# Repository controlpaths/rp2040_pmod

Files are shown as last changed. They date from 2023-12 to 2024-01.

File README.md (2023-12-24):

# RP2040 PMOD

The RP2040 PMOD is a PMOD-compatible board based on the [Raspberry PI](https://www.raspberrypi.com/) microcontroller, the [RP2040](https://www.raspberrypi.com/products/rp2040/)

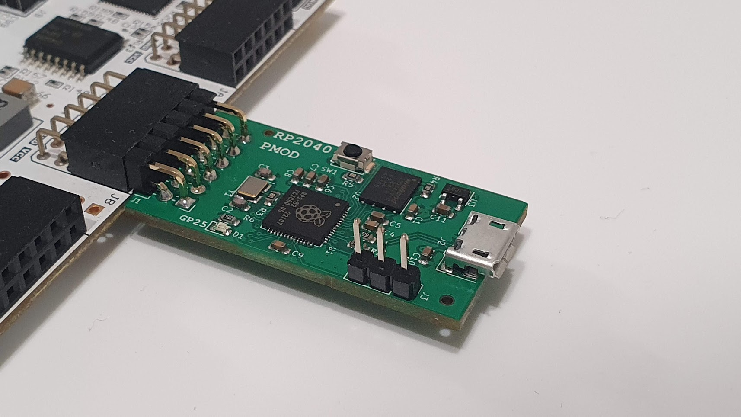
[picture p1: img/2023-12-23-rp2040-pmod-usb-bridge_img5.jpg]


The board has its own 3v3 LDO regulator, and the 3v3 pins of the PMOD connector are not connected.

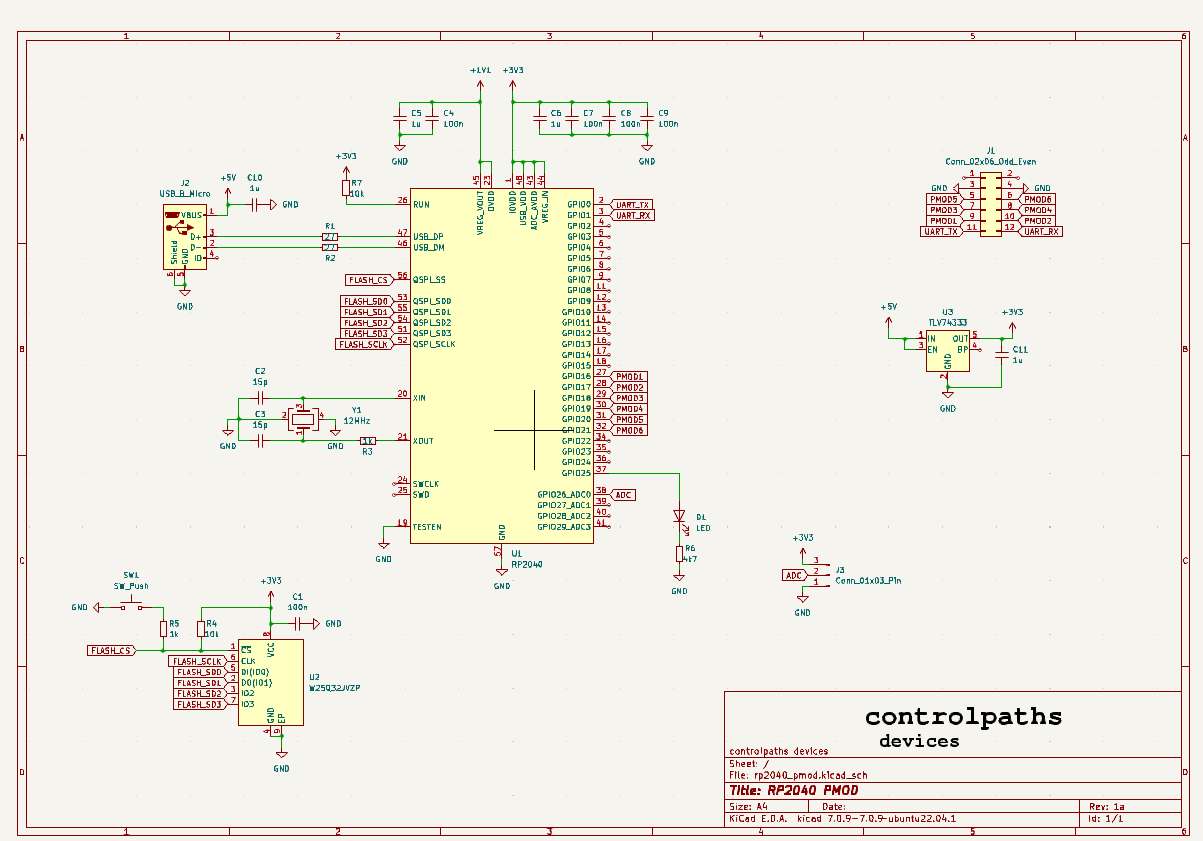
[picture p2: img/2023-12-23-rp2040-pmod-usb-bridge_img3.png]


PMOD connector.

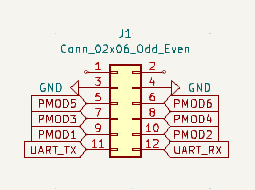
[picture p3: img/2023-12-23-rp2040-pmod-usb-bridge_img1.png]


## PMOD Connections

|PMOD PIN|Schematic|GPIO|Fuction|
|-|-|-|-|
|1|NC|--|--|
|2|NC|--|--|
|3|GND|--|GND|
|4|GND|--|GND|
|5|PMOD5|20|SPI0 RX / UART1 TX / I2C0 SDA|
|6|PMOD6|21|SPI0 CSn / UART1 RX / I2C0 SCL|
|7|PMOD3|18|SPI0 SCK / UART0 CTS / I2C1 SDA|
|8|PMOD4|19|SPI0 TX / UART0 RTS / I2C1 SCL|
|9|PMOD1|16|SPI0 RX / UART0 TX / I2C0 SDA|
|10|PMOD2|17|SPI0 CSn / UART0 RX / I2C0 SCL|
|11|UART_TX|0|SPI0 RX / UART0 TX / I2C0 SDA|
|12|UART_RX|1|SPI0 CSn / UART0 RX / I2C0 SCL|

## Examples

On the `/examples` folder you will find examples to program in this board. 

- [pico-uart-bridge](./examples/pico-uart-bridge/): Uses the RP2040 PMOD to generate two different UART interfaces in the PMOD PINS 5/6 and 11/12.

More examples soon!

## Get Yours

The RP2040 PMOD is open-source, so you can use the output files to manufacture your own in [JLCPCB](https://jlcpcb.com/?from=controlpath). You just need to compress the `output_files` directory, and upload it to [JLCPCB](https://jlcpcb.com/?from=controlpath). 

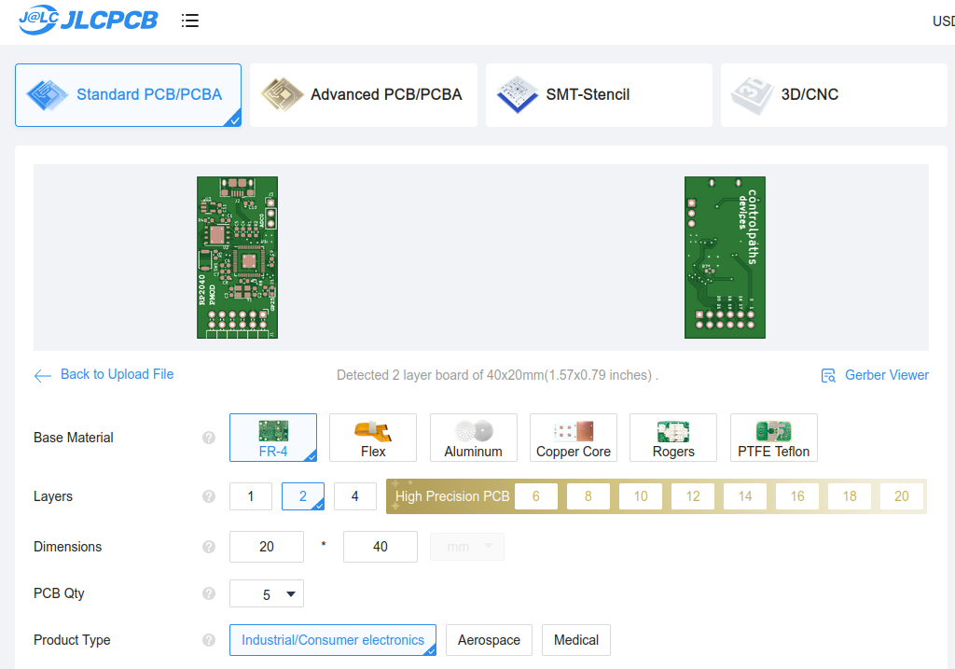
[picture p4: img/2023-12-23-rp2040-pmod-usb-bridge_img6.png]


Remember to change the Surface Finish to **LeadFree HASL** to make your board ROHS compliant.

Then you have to add the PCB Assembly service and upload the [centroid](./kicad/output_files/rp2040_pmod-all-pos.csv) file, and the [BOM](./kicad/output_files/bom.csv). 

In a few days, you will receive your board at home. If you want just one RP2040 PMOD, contact me.

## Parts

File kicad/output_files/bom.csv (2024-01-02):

# | Reference | Qty | Value | Footprint | DNP | JLCPCB Part #
1 | C1, C4, C7, C8, C9 | 5 | 100n | Capacitor_SMD:C_0603_1608Metric
2 | C2, C3 | 2 | 15p | Capacitor_SMD:C_0603_1608Metric
3 | C5, C6, C10, C11 | 4 | 1u | Capacitor_SMD:C_0603_1608Metric
4 | D1 | 1 | LED | LED_SMD:LED_0603_1608Metric
5 | J1 | 1 | Conn_02x06_Odd_Even | Connector_PinHeader_2.54mm:PinHeader_2x06_P2.54mm_Horizontal
6 | J2 | 1 | USB_B_Micro | Connector_USB:USB_Micro-B_Amphenol_10118193-0001LF_Horizontal |  | C132562
7 | J3 | 1 | Conn_01x03_Pin | Connector_PinHeader_2.54mm:PinHeader_1x03_P2.54mm_Vertical
8 | R1, R2 | 2 | 27 | Resistor_SMD:R_0603_1608Metric
9 | R3, R5 | 2 | 1k | Resistor_SMD:R_0603_1608Metric
10 | R4, R7 | 2 | 10k | Resistor_SMD:R_0603_1608Metric
11 | R6 | 1 | 4k7 | Resistor_SMD:R_0603_1608Metric
12 | SW1 | 1 | SW_Push | Button_Switch_SMD:SW_Push_SPST_NO_Alps_SKRK |  | C115357
13 | U1 | 1 | RP2040 | Package_DFN_QFN:QFN-56-1EP_7x7mm_P0.4mm_EP3.2x3.2mm
14 | U2 | 1 | W25Q32JVZP | Package_SON:WSON-8-1EP_6x5mm_P1.27mm_EP3.4x4.3mm |  | C2940197
15 | U3 | 1 | TLV74333 | Package_TO_SOT_SMD:SOT-23-5 |  | C408972
16 | Y1 | 1 | 12MHz | Crystal:Crystal_SMD_3225-4Pin_3.2x2.5mm |  | C524716

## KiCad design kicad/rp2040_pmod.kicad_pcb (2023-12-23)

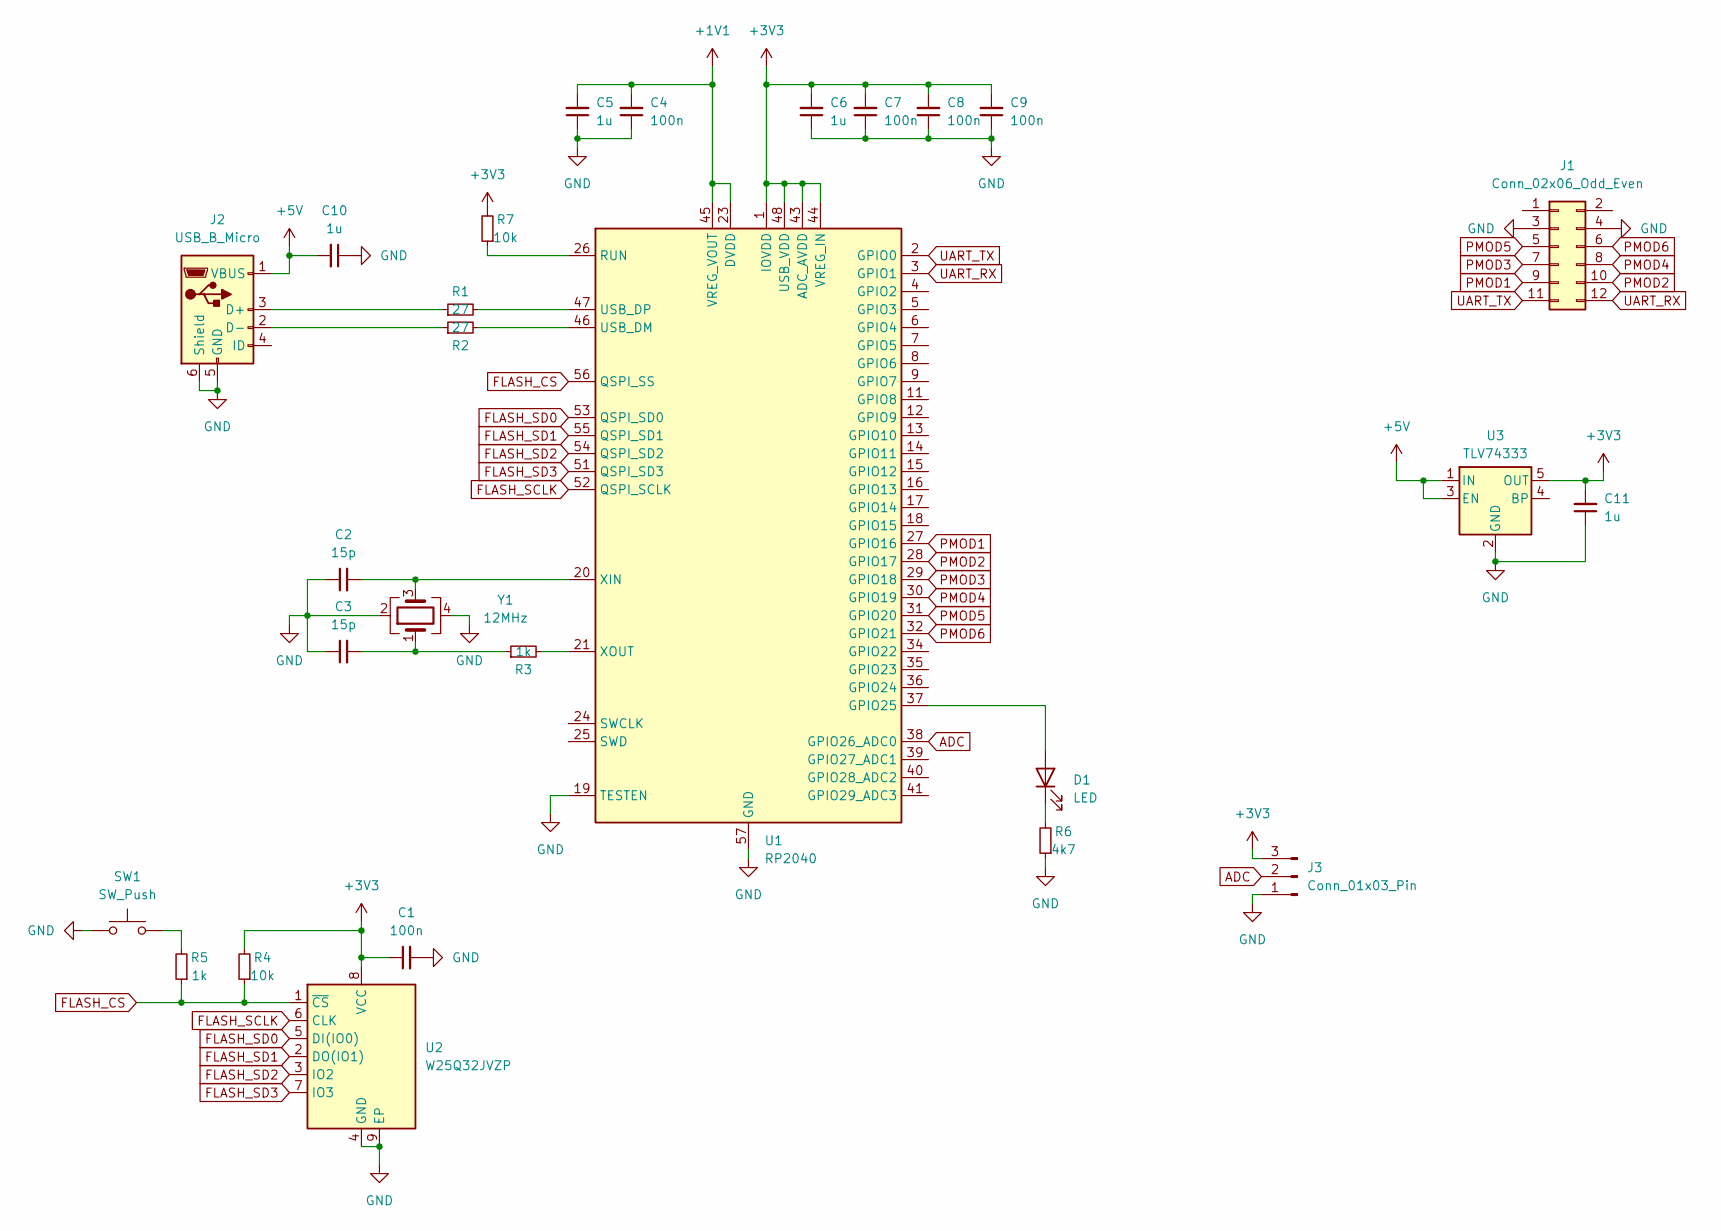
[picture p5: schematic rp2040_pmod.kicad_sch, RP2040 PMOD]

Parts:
C1, C4, C7, C8, C9: 100n; C_0603_1608Metric
C2, C3: 15p; C_0603_1608Metric
C5, C6, C10, C11: 1u; C_0603_1608Metric
D1: LED; LED_0603_1608Metric
J1: Conn_02x06_Odd_Even; PinHeader_2x06_P2.54mm_Horizontal
J2: USB_B_Micro; USB_Micro-B_Amphenol_10118193-0001LF_Horizontal; JLCPCB Part # C132562
J3: Conn_01x03_Pin; PinHeader_1x03_P2.54mm_Vertical
R1, R2: 27; R_0603_1608Metric
R3, R5: 1k; R_0603_1608Metric
R4, R7: 10k; R_0603_1608Metric
R6: 4k7; R_0603_1608Metric
SW1: SW_Push; SW_Push_SPST_NO_Alps_SKRK; JLCPCB Part # C115357
U1: RP2040; QFN-56-1EP_7x7mm_P0.4mm_EP3.2x3.2mm
U2: W25Q32JVZP; WSON-8-1EP_6x5mm_P1.27mm_EP3.4x4.3mm; JLCPCB Part # C2940197
U3: TLV74333; SOT-23-5; JLCPCB Part # C408972
Y1: 12MHz; Crystal_SMD_3225-4Pin_3.2x2.5mm; JLCPCB Part # C524716

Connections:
+1V1: C4.2, C5.2, U1.23 (DVDD), U1.45 (VREG_VOUT), U1.50 (DVDD)
+3V3: C1.1, C6.2, C7.2, C8.2, C9.2, C11.2, J3.3, R4.2, R7.2, U1.1 (IOVDD), U1.10 (IOVDD), U1.22 (IOVDD), U1.33 (IOVDD), U1.42 (IOVDD), U1.43 (ADC_AVDD), U1.44 (VREG_IN), U1.48 (USB_VDD), U1.49 (IOVDD), U2.8 (VCC), U3.5 (OUT)
+5V: C10.2, J2.1 (VBUS), U3.1 (IN), U3.3 (EN)
ADC: J3.2, U1.38 (GPIO26_ADC0)
FLASH_CS: R4.1, R5.1, U1.56 (QSPI_SS), U2.1 (~CS)
FLASH_SCLK: U1.52 (QSPI_SCLK), U2.6 (CLK)
FLASH_SD0: U1.53 (QSPI_SD0), U2.5 (DI(IO0))
FLASH_SD1: U1.55 (QSPI_SD1), U2.2 (DO(IO1))
FLASH_SD2: U1.54 (QSPI_SD2), U2.3 (IO2)
FLASH_SD3: U1.51 (QSPI_SD3), U2.7 (IO3)
GND: C1.2, C2.1, C3.1, C4.1, C5.1, C6.1, C7.1, C8.1, C9.1, C10.1, C11.1, J1.3, J1.4, J2.5 (GND), J2.6 (Shield), J3.1, R6.1, SW1.1, U1.19 (TESTEN), U1.57 (GND), U2.4 (GND), U2.9 (EP), U3.2 (GND), Y1.2, Y1.4
unnamed: C3.2, R3.1, Y1.1
unnamed: D1.2 (A), U1.37 (GPIO25)
unnamed: D1.1 (K), R6.2
unnamed: J2.3 (D+), R1.1
unnamed: J2.2 (D-), R2.1
unnamed: R5.2, SW1.2
unnamed: R7.1, U1.26 (RUN)
unnamed: R2.2, U1.46 (USB_DM)
unnamed: R1.2, U1.47 (USB_DP)
unnamed: C2.2, U1.20 (XIN), Y1.3
unnamed: R3.2, U1.21 (XOUT)
PMOD1: J1.9, U1.27 (GPIO16)
PMOD2: J1.10, U1.28 (GPIO17)
PMOD3: J1.7, U1.29 (GPIO18)
PMOD4: J1.8, U1.30 (GPIO19)
PMOD5: J1.5, U1.31 (GPIO20)
PMOD6: J1.6, U1.32 (GPIO21)
UART_RX: J1.12, U1.3 (GPIO1)
UART_TX: J1.11, U1.2 (GPIO0)

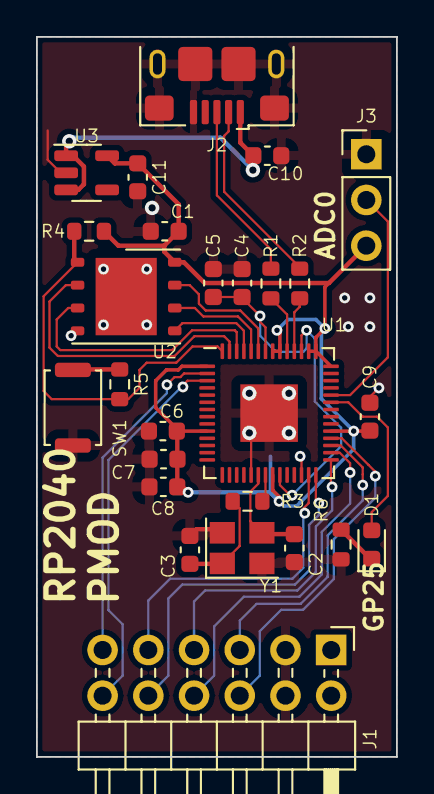
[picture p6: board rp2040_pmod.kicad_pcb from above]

Board: 2 copper layers, 20.0 x 40.0 mm, 27 parts (1 on the bottom side), 30 nets.

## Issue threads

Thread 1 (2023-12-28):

BOM and POS missing from Output_Files

no-shad, 2023-12-28:
404 error obtaining BOM

disdi, 2024-01-01:
same issue here .
I checked the previous commits and could not find BOM and POS files anywhere.

controlpaths, 2024-01-02:
Hi,
I just added the files.
Thanks!

controlpaths, 2024-01-02:
Files uploaded on main branch

Closed 2024-01-02.

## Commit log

2023-12-23 uploaded kicad files of the first version
    [rp2040_pmod-B_Cu.gbr, rp2040_pmod-B_Mask.gbr, rp2040_pmod-B_Paste.gbr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]
2023-12-23 added pico-uart-bridge example as a submodule
2024-01-02 fixed gitignore to add bom and pos file
    [bom.csv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]
